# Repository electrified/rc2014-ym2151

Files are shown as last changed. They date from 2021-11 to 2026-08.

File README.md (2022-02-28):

# OPM Tone Generator (AKA YM2151 Sound card) for RC2014/RC40 bus computers

## The board
RC40 bus OPM FM Sound card.

## Features
- FM Operator Type M (OPM)
- 4 operators
- 8 algorithms
- 8 notes
- Stereo output

## History
The YM2151 tone generator and accompanying YM3012 stereo DAC have been used in several computer systems.
Most notably the Sharp X68000 and Yamaha's CX5M MSX computer, along with a number of arcade boards.
More recently the retro inspired Commander X16 currently has one in it's design.

Yamaha's DX21, DX27 and DX100 synthesisers used a derivative IC which is very similar.

## What music files can be played back?
- YM2151 VGM files (using vgmplayer)
- Sharp X68000 MDX files (using mdxplay https://github.com/electrified/mdxplay-rc2014)

## Bill Of Materials
Download the latest Documentation zip from the releases section. This contains a HTML iBOM in the BOM folder.

## Gerbers
Download the latest JLCPCB zip from the releases section. This contains standard Gerbers.

## Sources / attribution
Beep program modified from https://commander-cx16.fandom.com/wiki/Beep

vgmplayer modified from Marco's version at https://groups.google.com/g/rc2014-z80/c/9nHnETJzGKU/m/z1A33J_GBAAJ, in turn modified from jblang's version at https://github.com/jblang/SN76489/blob/master/examples/vgmplayer.asm

KiCad Github actions
https://github.com/INTI-CMNB/kibot
https://github.com/neilenns/KiBot-CICD-Template
https://github.com/neilenns/CJ4-Electrical-Panel

## Background reading/ viewing
https://ayce.dev/emptyx16.html#9f41h---ym2151-register-data-w--status-r

https://ayce.dev/emptyx16.html#ym2151-fm-operator-type-m-opm

https://www.youtube.com/watch?v=BG6q53p7Z10

https://www.youtube.com/watch?v=GnbT23wGcIA

https://www.youtube.com/watch?v=C8K_VtGyjHM

https://vgmrips.net/wiki/OPM_File_Format

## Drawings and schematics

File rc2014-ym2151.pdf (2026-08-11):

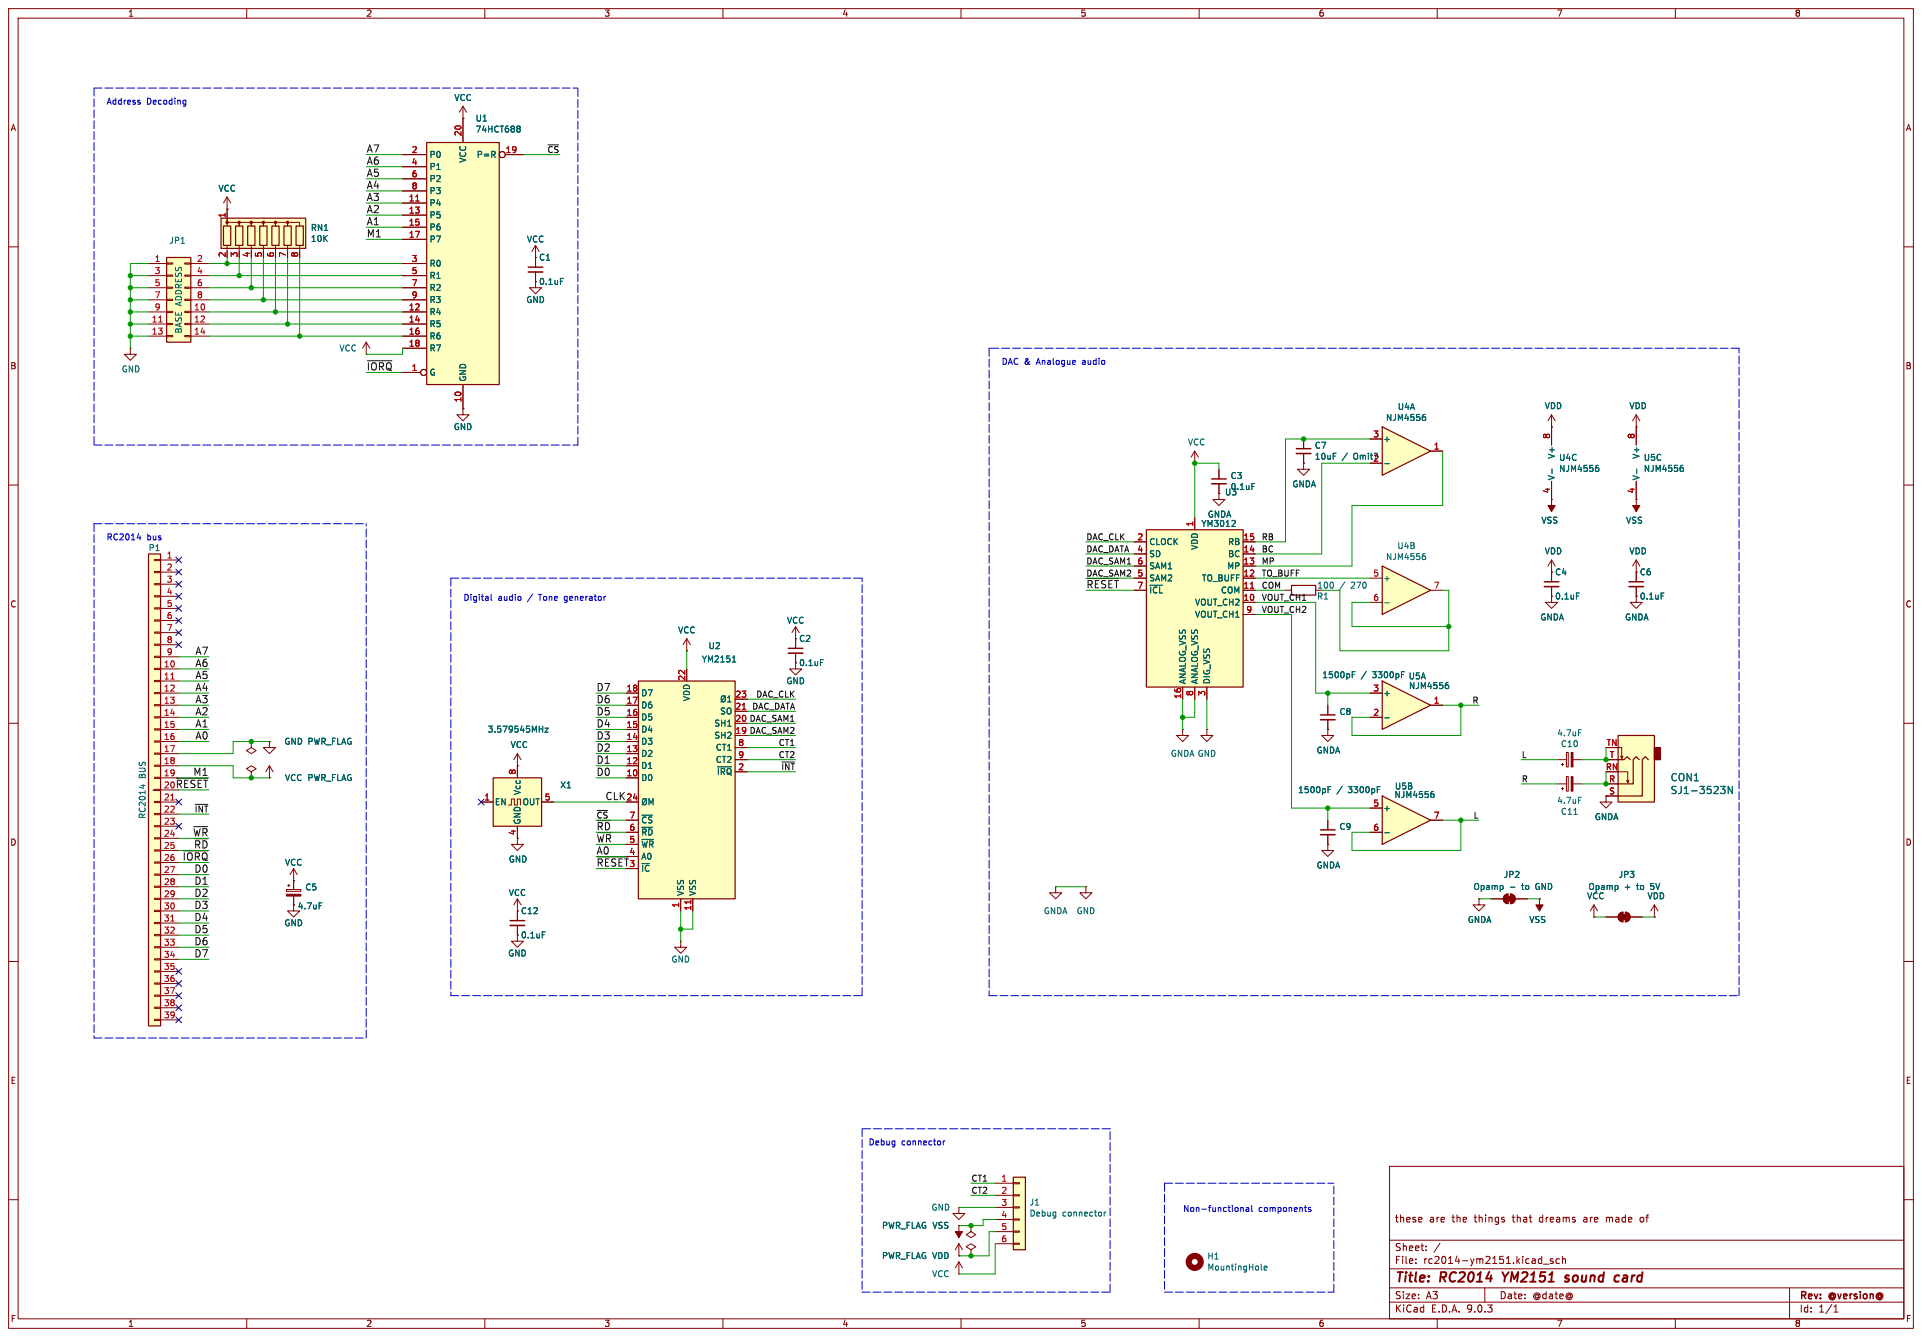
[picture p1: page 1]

3 RB 15 BC 14 MP 13 TO_BUFF 12 COM 11 VOUT_CH2 10 VOUT_CH1 9 U5C
1500pF / 3300pF GNDAC3

3 RB 15 BC 14 MP 13 TO_BUFF 12 COM 11 VOUT_CH2 10 VOUT_CH1 9 U3 YM3012 C8
GND

1 VSS 11 SO 21 SH1 20 SH2 19 CT1 8 CT2 9 ~{IRQ}2 U2 YM2151 VCC

1 VSS 11 SO 21 SH1 20 SH2 19 CT1 8 CT2 9 ~{IRQ}2 VCC

these are the things that dreams are made of VCC
H1 MountingHole VSS

File: rc2014-ym2151.kicad_sch Sheet: /
Id: 1/1 Title: RC2014 YM2151 sound card

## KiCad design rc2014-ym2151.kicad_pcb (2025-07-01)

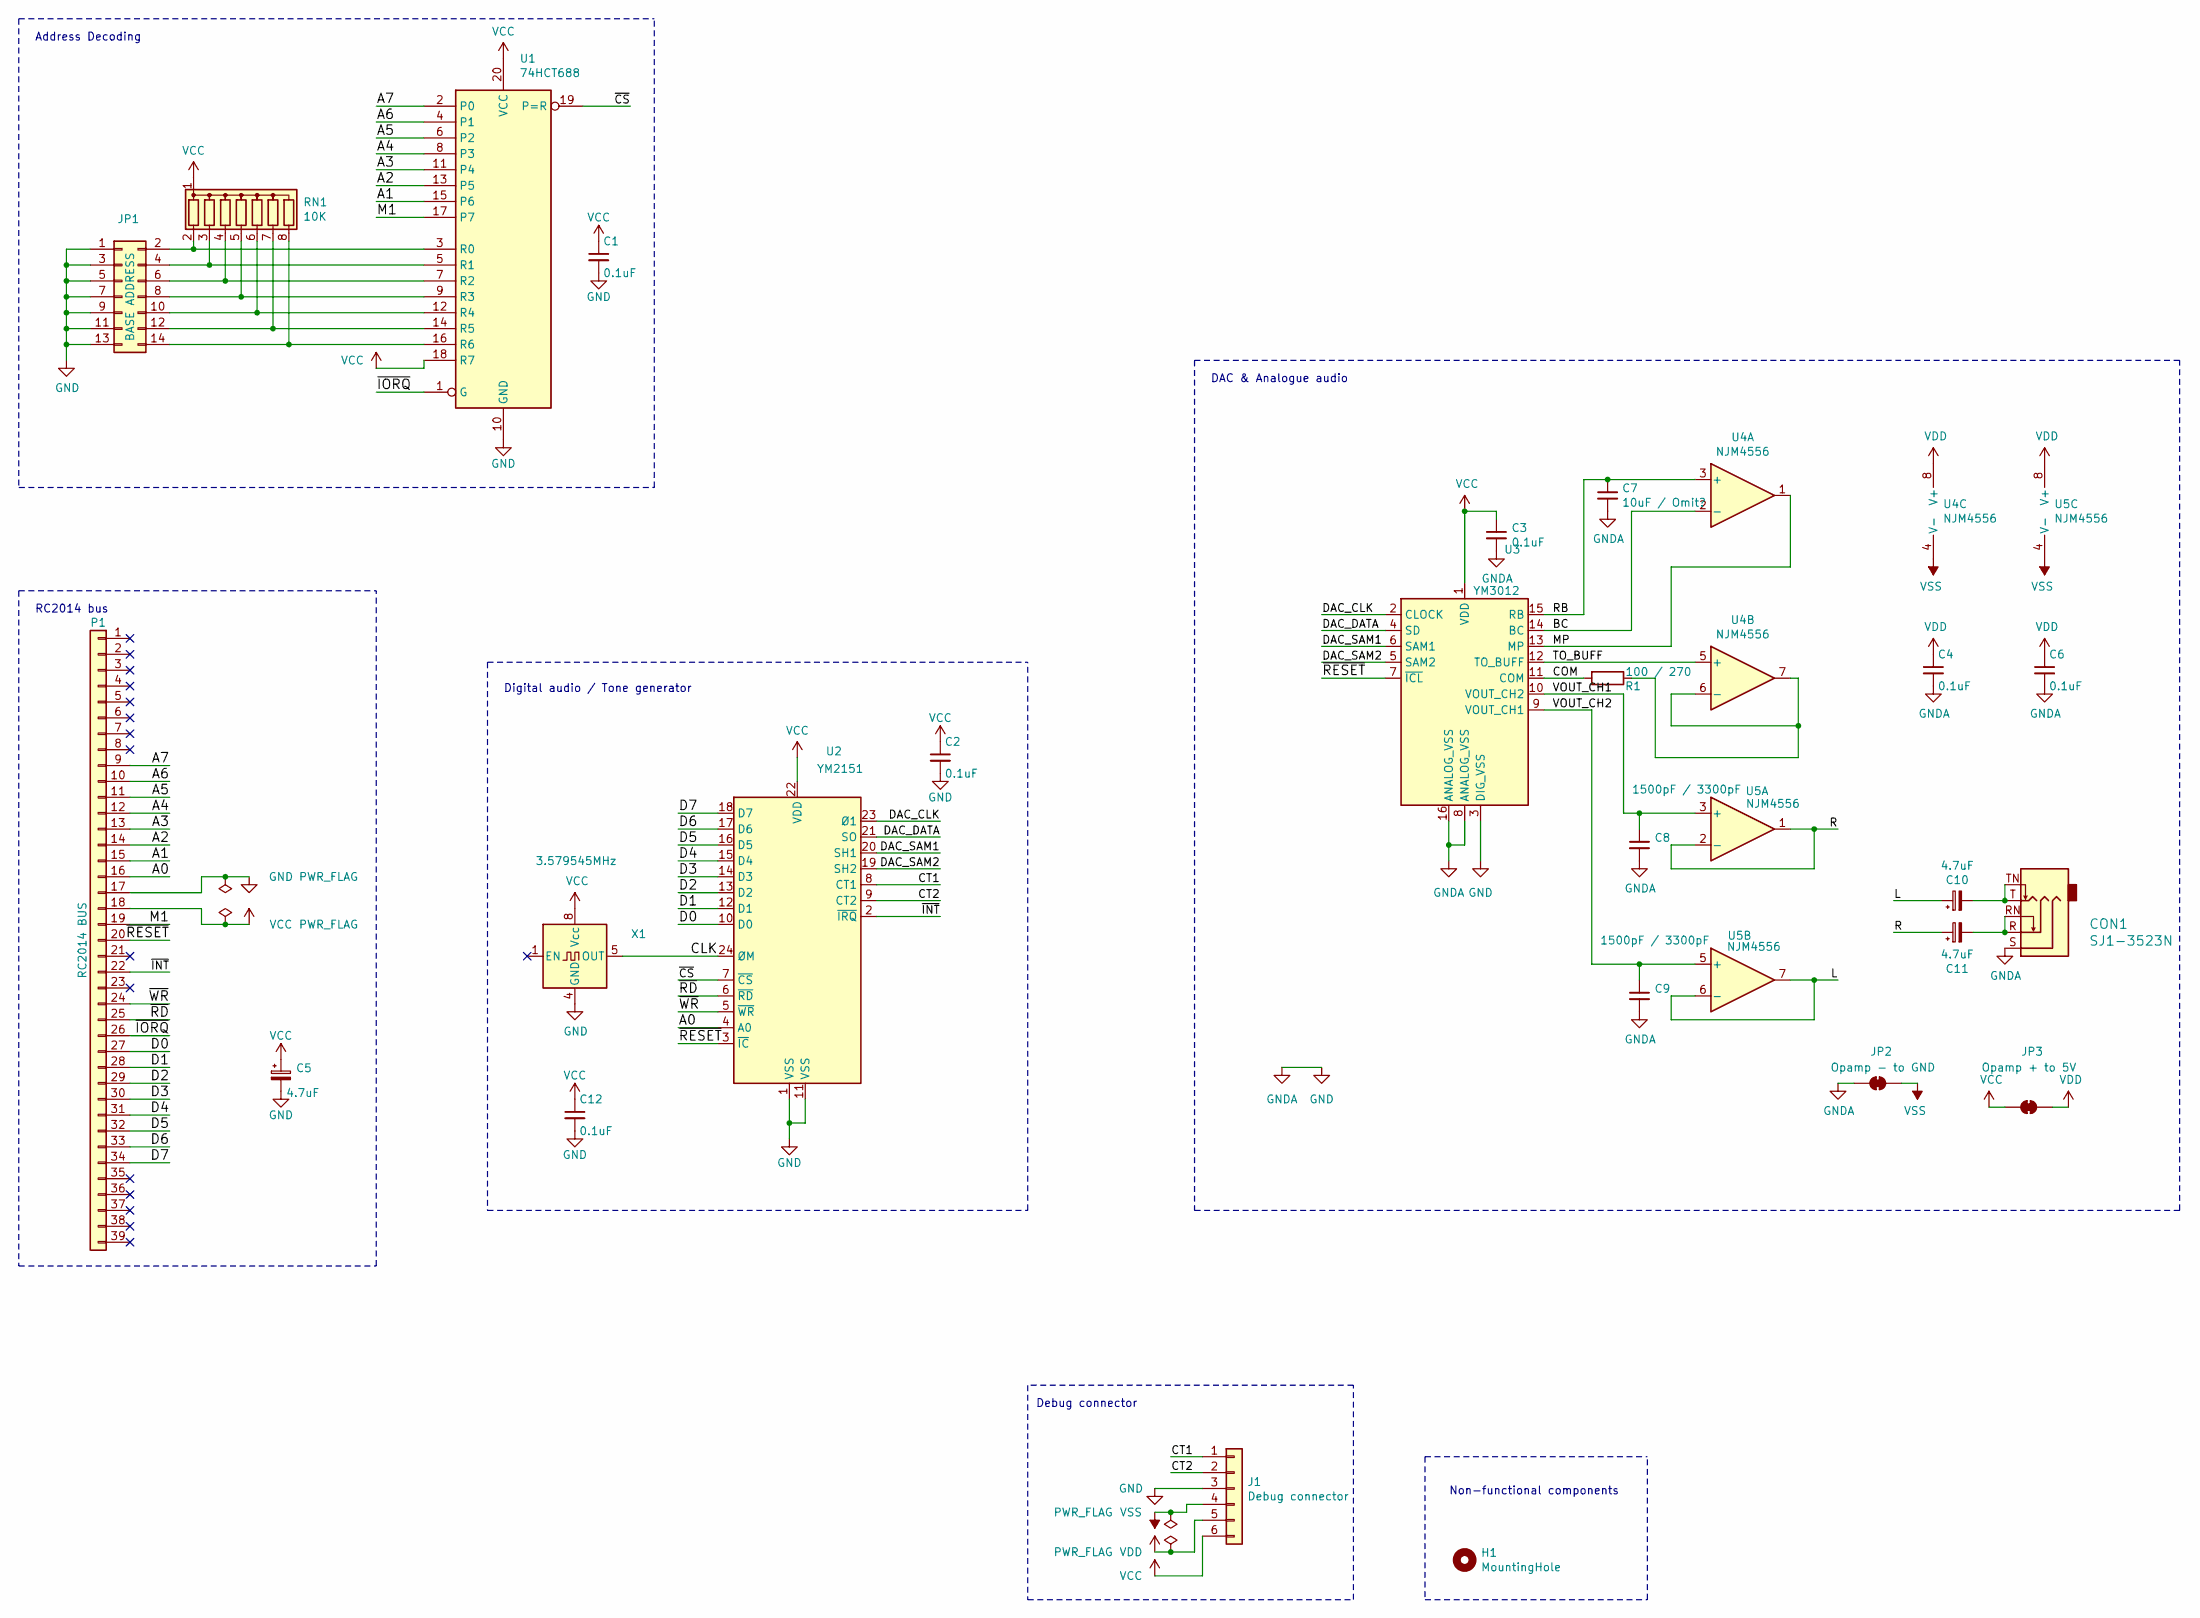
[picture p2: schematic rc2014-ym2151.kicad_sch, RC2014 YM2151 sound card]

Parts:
C1, C2, C3, C4, C6, C12: 0.1uF; C_Disc_D3.8mm_W2.6mm_P2.50mm
C5: 4.7uF; CP_Radial_D7.5mm_P2.50mm
C7: 10uF / Omit?; C_Radial_D4.0mm_H7.0mm_P1.50mm
C8, C9: 1500pF / 3300pF; C_Disc_D3.8mm_W2.6mm_P2.50mm
C10, C11: 4.7uF; CP_Radial_D5.0mm_P2.50mm
CON1: SJ1-3523N; Headphone_Jack_3.5mm_5_pin; MPN SJ1-3523N; Digi-Key_PN CP1-3523N-ND
H1: MountingHole; MountingHole_3.2mm_M3
J1: Debug connector; PinHeader_1x06_P2.54mm_Vertical
JP1: BASE ADDRESS; PinHeader_2x07_P2.54mm_Vertical
JP2: Opamp - to GND; SolderJumper-2_P1.3mm_Bridged2Bar_RoundedPad1.0x1.5mm
JP3: Opamp + to 5V; SolderJumper-2_P1.3mm_Bridged2Bar_RoundedPad1.0x1.5mm
P1: RC2014 BUS; PinHeader_1x39_P2.54mm_Vertical
R1: 100 / 270; R_Axial_DIN0204_L3.6mm_D1.6mm_P7.62mm_Horizontal
RN1: 10K; R_Array_SIP8
U1: 74HCT688; DIP-20_W7.62mm_Socket
U2: YM2151; DIP-24_W15.24mm
U3: YM3012; DIP-16_W7.62mm
U4, U5: NJM4556; DIP-8_W7.62mm_Socket
X1: 3.579545MHz; DIP-8_W7.62mm_Socket

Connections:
/A0: P1.16, U2.4 (A0)
/A1: P1.15, U1.15 (P6)
/A2: P1.14, U1.13 (P5)
/A3: P1.13, U1.11 (P4)
/A4: P1.12, U1.8 (P3)
/A5: P1.11, U1.6 (P2)
/A6: P1.10, U1.4 (P1)
/A7: P1.9, U1.2 (P0)
/BC: U3.14 (BC), U4.2 (-)
/CLK: U2.24 (ØM), X1.5 (OUT)
/COM: R1.2, U3.11 (COM)
/CT1: J1.1, U2.8 (CT1)
/CT2: J1.2, U2.9 (CT2)
/D0: P1.27, U2.10 (D0)
/D1: P1.28, U2.12 (D1)
/D2: P1.29, U2.13 (D2)
/D3: P1.30, U2.14 (D3)
/D4: P1.31, U2.15 (D4)
/D5: P1.32, U2.16 (D5)
/D6: P1.33, U2.17 (D6)
/D7: P1.34, U2.18 (D7)
/DAC_CLK: U2.23 (Ø1), U3.2 (CLOCK)
/DAC_DATA: U2.21 (SO), U3.4 (SD)
/DAC_SAM1: U2.20 (SH1), U3.6 (SAM1)
/DAC_SAM2: U2.19 (SH2), U3.5 (SAM2)
/L: C10.1, U5.6 (-), U5.7
/M1: P1.19, U1.17 (P7)
/MP: U3.13 (MP), U4.1
/R: C11.1, U5.1, U5.2 (-)
/RB: C7.1, U3.15 (RB), U4.3 (+)
/TO_BUFF: U3.12 (TO_BUFF), U4.5 (+)
/VOUT_CH1: C8.1, U3.10 (VOUT_CH2), U5.3 (+)
/VOUT_CH2: C9.1, U3.9 (VOUT_CH1), U5.5 (+)
/~CS: U1.19 (P=R), U2.7 (~CS)
/~INT: P1.22, U2.2 (~IRQ)
/~IORQ: P1.26, U1.1 (G)
/~RD: P1.25, U2.6 (~RD)
/~RESET: P1.20, U2.3 (~IC), U3.7 (~ICL)
/~WR: P1.24, U2.5 (~WR)
GND: C1.2, C2.2, C3.2, C4.2, C5.2, C6.2, C7.2, C8.2, C9.2, C12.2, CON1.S, J1.3, JP1.1, JP1.3, JP1.5, JP1.7, JP1.9, JP1.11, JP1.13, JP2.1 (A), P1.17, U1.10 (GND), U2.1 (VSS), U2.11 (VSS), U3.3 (DIG_VSS), U3.8 (ANALOG_VSS), U3.16 (ANALOG_VSS), X1.4 (GND)
unnamed: C10.2, CON1.T, CON1.TN
unnamed: C11.2, CON1.R, CON1.RN
unnamed: JP1.2, RN1.2 (R1), U1.3 (R0)
unnamed: JP1.4, RN1.3 (R2), U1.5 (R1)
unnamed: JP1.6, RN1.4 (R3), U1.7 (R2)
unnamed: JP1.8, RN1.5 (R4), U1.9 (R3)
unnamed: JP1.10, RN1.6 (R5), U1.12 (R4)
unnamed: JP1.12, RN1.7 (R6), U1.14 (R5)
unnamed: JP1.14, RN1.8 (R7), U1.16 (R6)
unnamed: R1.1, U4.6 (-), U4.7
VCC: C1.1, C2.1, C3.1, C5.1, C12.1, J1.6, JP3.1 (A), P1.18, RN1.1 (common), U1.18 (R7), U1.20 (VCC), U2.22 (VDD), U3.1 (VDD), X1.8 (Vcc)
VDD: C4.1, C6.1, J1.5, JP3.2 (B), U4.8 (V+), U5.8 (V+)
VSS: J1.4, JP2.2 (B), U4.4 (V-), U5.4 (V-)

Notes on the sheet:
Non-functional components
Digital audio / Tone generator
Debug connector
Address Decoding
DAC & Analogue audio
RC2014 bus

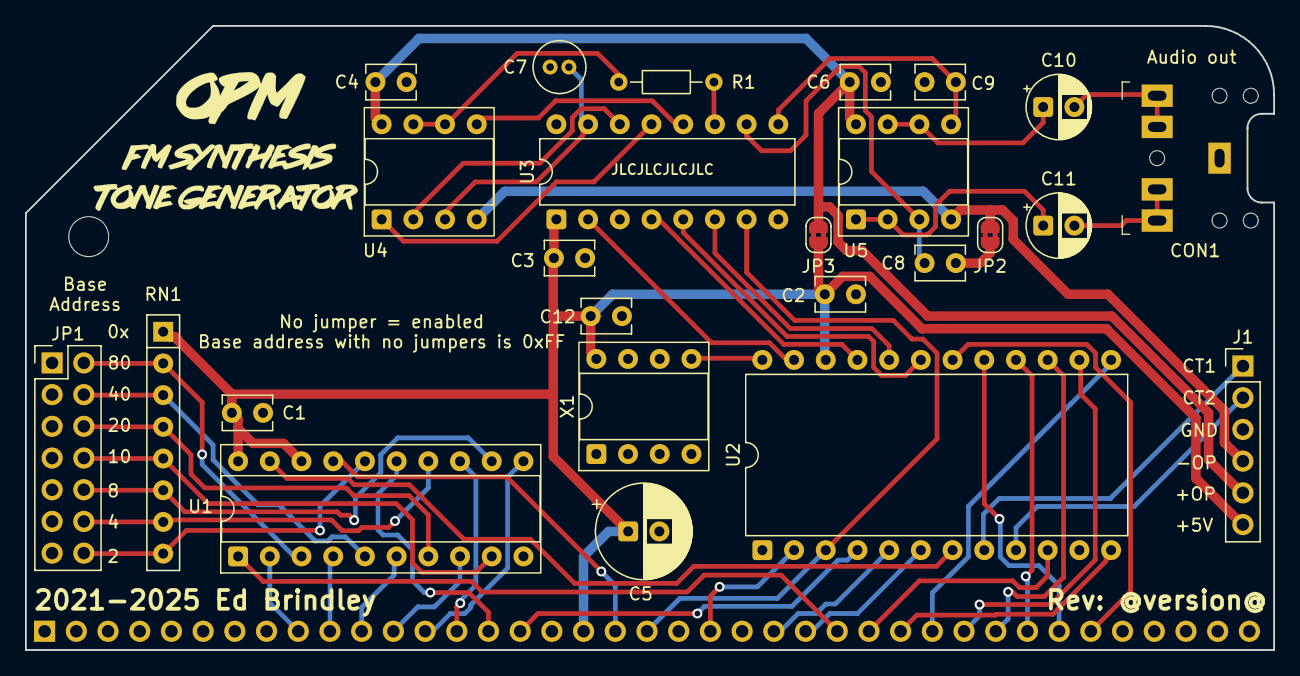
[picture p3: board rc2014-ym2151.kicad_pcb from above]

Board: 2 copper layers, 100.0 x 50.0 mm, 29 parts (1 on the bottom side), 53 nets.

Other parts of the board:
G1: LOGO; opm
G3: OSHW-Logo_11.4x12mm_SilkScreen

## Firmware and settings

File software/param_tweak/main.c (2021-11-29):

#include <stdlib.h>
#include <stdint.h>
#include <stdio.h>
#define REG_SEL_PORT 0xA0u
#define REG_DATA_PORT 0xA1u

#ifdef __SDCC
__sfr __at REG_SEL_PORT REG_SEL;
__sfr __at REG_DATA_PORT REG_DATA;
#else

unsigned char REG_SEL;
unsigned char REG_DATA;
#endif

struct operator
{
        uint8_t dt1_mul;
        uint8_t tl;
        uint8_t ks_ar;
        uint8_t ame_d1r;
        uint8_t dt2_d2r;
        uint8_t d1l_rr;
};

uint8_t operator_getDT1(struct operator *o) { return (o->dt1_mul >> 4) & 0x07; } // DeTune 1
void operator_setDT1(struct operator *o, uint8_t val) { o->dt1_mul = (o->dt1_mul & 0x0f) | (val << 4); }
uint8_t operator_getMUL(struct operator *o) { return o->dt1_mul & 0x0f; } // detune MULtiplier
void operator_setMUL(struct operator *o, uint8_t val) { o->dt1_mul = (o->dt1_mul & 0xf0) | (val & 0x0f); }
uint8_t operator_getTL(struct operator *o) { return o->tl & 0x7f; }       // Total Level (envelope)
uint8_t operator_getKS(struct operator *o) { return o->ks_ar >> 6; }      // Key Scaling
uint8_t operator_getAR(struct operator *o) { return o->ks_ar & 0x1f; }    // Attack Rate (envelope)
void operator_setAR(struct operator *o, uint8_t val) { o->ks_ar = (o->ks_ar & 0xc0) | (val & 0x1f); }
uint8_t operator_getAME(struct operator *o) { return o->ame_d1r >> 7; }   // AMS Enable
uint8_t operator_getD1R(struct operator *o) { return o->ame_d1r & 0x1f; } // Decay Rate 1
void operator_setD1R(struct operator *o, uint8_t val) { o->ame_d1r = (o->ame_d1r & 0xc0) | (val & 0x1f); }
uint8_t operator_getDT2(struct operator *o) { return o->dt2_d2r >> 6; }   // DeTune 2
uint8_t operator_getD2R(struct operator *o) { return o->dt2_d2r & 0x1f; } // Decay Rate 2
uint8_t operator_getD1L(struct operator *o) { return o->d1l_rr >> 4; }    // Decay Level 1
void operator_setD1L(struct operator *o, uint8_t val) { o->d1l_rr = (o->d1l_rr & 0x0f) | (val << 4); }
uint8_t operator_getRR(struct operator *o) { return o->d1l_rr & 0x0f; } // Release Rate
void operator_setRR(struct operator *o, uint8_t val) { o->d1l_rr = (o->d1l_rr & 0xf0) | (val & 0x0f); }

void print_operator(struct operator *o)
{
        printf("Detune (1) %d\n", operator_getDT1(o));
        printf("Phase Multiply %d\n", operator_getMUL(o));
        printf("Total Level %d\n", operator_getTL);
        printf("Key Scaling %d\n", operator_getKS);
        printf("Attack Rate %d\n", operator_getAR);
        printf("AMS Enable %d\n", operator_getAME);
        printf("First Decay Rate %d\n", operator_getD1R);
        printf("Second Detune %d\n", operator_getDT2);
        printf("Second Decay Rate %d\n", operator_getD2R);
        printf("First Decay Level %d\n", operator_getD1L);
        printf("Release Rate %d\n", operator_getRR);
}

struct voice
{
        uint8_t ne_nfrq;
        uint8_t lfrq;
        uint8_t pmd_amd;
        uint8_t ct_w;
        uint8_t rl_fb_con;
        uint8_t pms_ams;

        // uint8_t slot_mask;
        struct operator operators[4];
};

uint8_t voice_getNE(struct voice *v) { return v->ne_nfrq >> 7; }
uint8_t voice_getNFRQ(struct voice *v) { return v->ne_nfrq & 0x1f; }
uint8_t voice_getIsPhaseOrAmplitude(struct voice *v) { return v->pmd_amd >> 7; }
uint8_t voice_getMD(struct voice *v) { return v->pmd_amd & 0x7f; }
uint8_t voice_getW(struct voice *v) { return v->ct_w & 0x03; }
uint8_t voice_getRL(struct voice *v) { return (v->rl_fb_con >> 6) & 0x02; }
void voice_setRL(struct voice *v, uint8_t val) { v->rl_fb_con = (v->rl_fb_con & 0x3f) | (val << 6); }

uint8_t voice_getFB(struct voice *v) { return (v->rl_fb_con >> 3) & 0x07; }
uint8_t voice_getCON(struct voice *v) { return v->rl_fb_con & 0x07; }
uint8_t voice_getPMS(struct voice *v) { return (v->pms_ams >> 4) & 0x07; }
uint8_t voice_getAMS(struct voice *v) { return v->pms_ams & 0x02; }

void print_voice(struct voice *v)
{
        printf("Noise Enable %d\n", voice_getNE(v));
        printf("Noise Frequency %d\n", voice_getNFRQ(v));
        printf("Low Frequency %d\n", v->lfrq);
        printf("Phase or aplitude modulation %d\n", voice_getIsPhaseOrAmplitude(v));
        printf("Modulation depth %d\n", voice_getMD(v));
        printf("Waveform %d\n", voice_getW(v));
        printf("Right/Left %d\n", voice_getRL(v));
        printf("Self Feedback Level %d\n", voice_getFB(v));
        printf("Connection (AKA algorithm) %d\n", voice_getCON(v));
        printf("Phase modulation Sensitivity %d\n", voice_getPMS(v));
        printf("Amplitude Modulation Sensitivity %d\n", voice_getAMS(v));
}

void write_register(uint8_t reg, uint8_t value)
{
        printf("IO reg: %#02x val: %#02x\n", reg, value);
        REG_SEL = reg;
        REG_DATA = value;
}

void setNote(uint8_t channel, uint8_t note) {
        write_register(0x28 + channel, note);
}

void note_on_off(uint8_t channel, uint8_t slots)
{
        write_register(0x8, (slots << 3) + (channel & 0x7));
}

uint8_t getRegister(uint8_t base, uint8_t channel, uint8_t operator) {
        return base + (8 * operator) + channel;
}

void main()
{
        // 8 voices, each with 4 operators =32 slots
        struct voice v;
        // Beep
        // 280 DATA &H20, &HC0
        voice_setRL(&v, 0x3);
        write_register(0x20, v.rl_fb_con);
        // 290 DATA &H58, &H01
        // 58h == 40h + 18h(24)
        // channel 8, carrier 1 (operator 3 of 4), 
        operator_setMUL(&v.operators[2], 0x01);
        write_register(getRegister(0x40, 7, 2), v.operators[2].dt1_mul);
        // 300 DATA &H98, &H1F
        operator_setAR(&v.operators[2], 0x1f);
        write_register(getRegister(0x80, 7, 2), v.operators[2].ks_ar);
        // 310 DATA &HB8, &H0D
        operator_setD1R(&v.operators[2], 0x0d);
        write_register(getRegister(0xA0, 7, 2), v.operators[2].ame_d1r);
        // 320 DATA &HF8, &HF6
        operator_setD1L(&v.operators[2], 0x0f);
        operator_setRR(&v.operators[2], 0x06);
        write_register(getRegister(0xE0, 7, 2), v.operators[2].ame_d1r);

        setNote(7,0x3a);
        note_on_off(7, 0);
        note_on_off(7, 0b1111);

        //todo wait

        setNote(7,0x44);
        note_on_off(7, 0);
        note_on_off(7, 0b1111);

        print_voice(&v);
        
        //todo wait

        //  while(1) {
        //          // read keyboard
        //  }
}

void print_parameters()
{
}

/*
* Initialise YM
*/
void init(struct voice *v)
{
        // write_register()
}

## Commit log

2021-11-09 First version that looks reasonable....
    [rc2014-ym2151.kicad_pcb, rc2014-ym2151.sch]
2021-11-09 Add actions gerber build
2021-11-11 Use git submode for library
    [rc2014-ym2151.kicad_pcb, rc2014-ym2151.sch]
2021-11-16 Fix up silkscreen, move opamp location slightly
    [rc2014-ym2151.kicad_pcb]
2021-11-19 Add ability to power opamps separately
    [rc2014-ym2151.kicad_pcb, rc2014-ym2151.sch]
2021-11-20 further updates
    [rc2014-ym2151.kicad_pcb]
2021-11-20 Move some component references
    [rc2014-ym2151.kicad_pcb, rc2014-ym2151.sch]
2021-11-20 Switch to using KiBot-CICD-Template
    [rc2014-ym2151.kicad_pcb, rc2014-ym2151.sch]
2021-11-20 hardcode pcb date
    [rc2014-ym2151.kicad_pcb]
2021-11-20 add date palaceholder back
    [rc2014-ym2151.kicad_pcb]
2021-11-20 move version tag
    [rc2014-ym2151.kicad_pcb]
2021-11-21 Tidy schematic and readme
    [rc2014-ym2151.kicad_pcb, rc2014-ym2151.sch]
2021-11-24 Update build script to latest released version, and PCB missed from previous commit
    [rc2014-ym2151.kicad_pcb]
2021-11-27 Add unmodified vgmplay
    [rc2014-ym2151.kicad_pcb]
2021-12-17 add bits lurking around
    [rc2014-ym2151.kicad_pcb, rc2014-ym2151.sch]
2021-12-31 Update to Kicad 6
    [rc2014-ym2151.kicad_pcb, rc2014-ym2151.kicad_sch, rc2014-ym2151.sch]
2022-01-09 schematic tidyup
    [rc2014-ym2151.kicad_sch]
2022-02-21 Tidy up schematic further
    [rc2014-ym2151.kicad_pcb, rc2014-ym2151.kicad_sch]
2022-02-21 Update sch paths to use kicad 6 extension
2022-02-21 remove silk that clashes, another date fix
    [rc2014-ym2151.kicad_pcb]
2022-02-22 date replacement
    [rc2014-ym2151.kicad_pcb, rc2014-ym2151.kicad_sch]
2022-02-28 Use Aisler DRC
    Update README.md
    change board outline
    wip
    [rc2014-ym2151.kicad_pcb]
2022-03-02 remove dubious silkscreen
    [rc2014-ym2151.kicad_pcb]
2025-07-01 migrate to kicad 9 - fix most of the ERC and DRC issues, use current library symbols/footprints
    [rc2014-ym2151.kicad_pcb, rc2014-ym2151.kicad_sch]
2025-07-01 update copyright date
    [rc2014-ym2151.kicad_pcb]
2025-07-20 kicad 9 updates
    [rc2014-ym2151.kicad_sch]
